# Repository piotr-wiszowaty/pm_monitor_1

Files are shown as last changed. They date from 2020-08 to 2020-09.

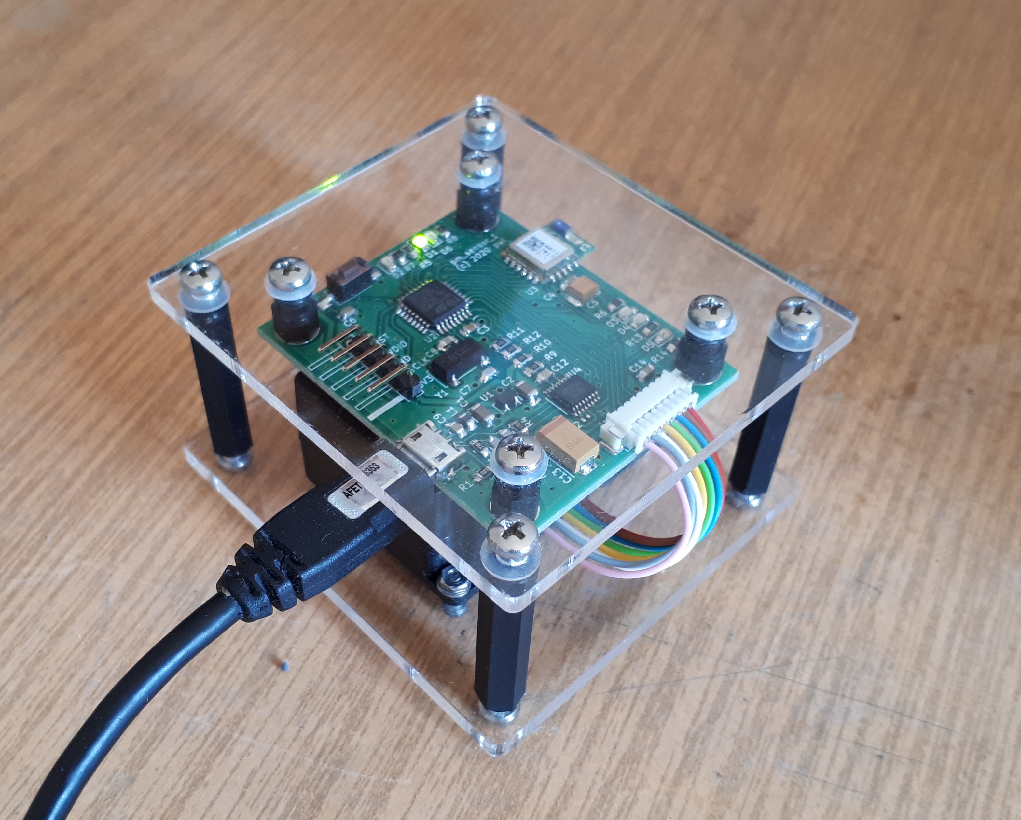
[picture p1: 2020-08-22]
pics/pm_monitor_1.jpg

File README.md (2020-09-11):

pm_monitor_1
============

A particulate matter monitor with BLE and UART interfaces.

The device is based on this [sensor](https://www.dfrobot.com/product-1272.html).
The measured particle concentrations are reported periodically over UART
(FDTI chip based interface) and over BLE. The included server listens for
the incoming BLE reports and stores them in an [InfluxDB](https://www.influxdata.com/) database.

Firmware
--------

The firmware is based on [Mecrisp-Stellaris Forth](http://mecrisp.sourceforge.net/).
Flashing firmware can be done using a communication program (minicom, picocom, etc):

0. flash the Mecrisp-Stellaris Forth core (see note below),
1. send `flash.forth`,
2. send `turnkey.forth`,
3. reset the device.

The microcontroller register and bit field constants can be downloaded from [here](https://github.com/piotr-wiszowaty/comfoh).

Note that to utilize hardware flow control (as in `uc/term.sh`) you need to enable USART2 RTS/CTS
lines in the Mecrisp-Stellaris Forth core.

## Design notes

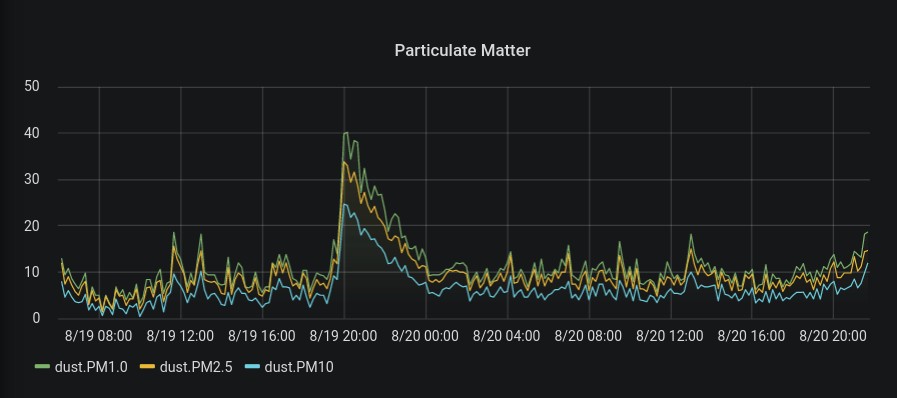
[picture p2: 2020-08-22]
pics/pm_plot.jpg

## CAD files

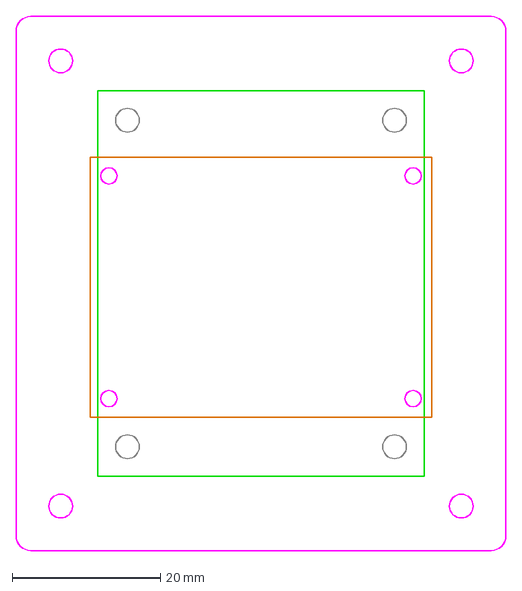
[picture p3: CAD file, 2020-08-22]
enclosure/pm_monitor_1.dxf
66.0 x 72.0 mm

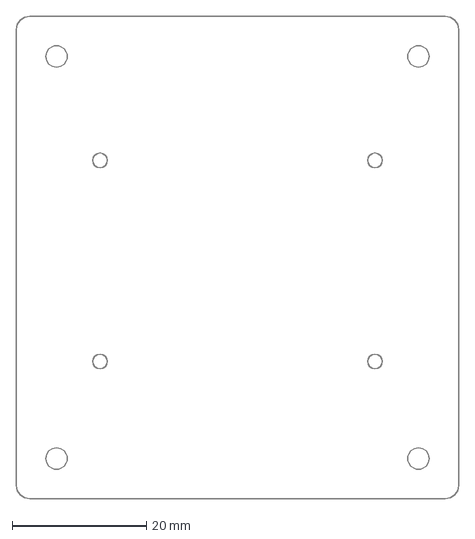
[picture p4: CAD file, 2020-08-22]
enclosure/pm_monitor_1_bot.dxf
66.0 x 72.0 mm

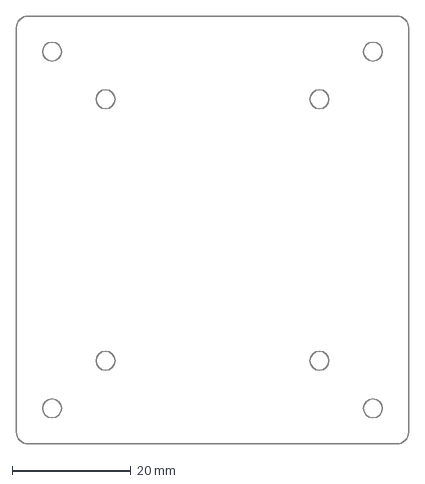
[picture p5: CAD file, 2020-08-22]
enclosure/pm_monitor_1_top.dxf
66.0 x 72.0 mm

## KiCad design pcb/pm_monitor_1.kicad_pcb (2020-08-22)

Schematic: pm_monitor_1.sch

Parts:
C1, C2: 1uF; C_1206_3216Metric_Pad1.42x1.75mm_HandSolder
C3, C9: 10nF; C_0805_2012Metric_Pad1.15x1.40mm_HandSolder
C4, C6, C12, C14: 100nF; C_0805_2012Metric_Pad1.15x1.40mm_HandSolder
C5: 10uF; CP_EIA-3528-21_Kemet-B_Pad1.50x2.35mm_HandSolder
C7, C8: 15pF; C_0805_2012Metric_Pad1.15x1.40mm_HandSolder
C10, C11: 47pF; C_0805_2012Metric_Pad1.15x1.40mm_HandSolder
C13: 330uF; CP_EIA-7343-31_Kemet-D_Pad2.25x2.55mm_HandSolder
D1: PWRLED; LED_0805_2012Metric_Pad1.15x1.40mm_HandSolder
D2, D6: LED; LED_0805_2012Metric_Pad1.15x1.40mm_HandSolder
D3: BTLED; LED_0805_2012Metric_Pad1.15x1.40mm_HandSolder
D4: TXLED; LED_0805_2012Metric_Pad1.15x1.40mm_HandSolder
D5: RXLED; LED_0805_2012Metric_Pad1.15x1.40mm_HandSolder
H1, H2, H3, H4: MountingHole; MountingHole_3.2mm_M3_Pad
J1: USB_B_Micro; USB_Micro-B_Molex_47346-0001
J2: SEN0177; Molex_PicoBlade_53261-0871_1x08-1MP_P1.25mm_Horizontal
J3: SWD; PinHeader_1x06_P2.54mm_Horizontal_HighProfile
L1: 600; L_0805_2012Metric_Pad1.15x1.40mm_HandSolder
R1: 100k; R_0805_2012Metric_Pad1.15x1.40mm_HandSolder
R2: 0; R_0402_1005Metric
R3, R4: 27; R_0805_2012Metric_Pad1.15x1.40mm_HandSolder
R5, R13: 100; R_0805_2012Metric_Pad1.15x1.40mm_HandSolder
R6, R7, R8, R14: 330; R_0805_2012Metric_Pad1.15x1.40mm_HandSolder
R9, R10, R11, R12: 10k; R_0805_2012Metric_Pad1.15x1.40mm_HandSolder
SW1: RESET; SW_SPST_FSMSM
U1: MCP1700-3302E_SOT23; SOT-23
U2: STM32G071KBT; LQFP-32_7x7mm_P0.8mm
U3: RN4871; Microchip_RN4871
U4: FT230XS; SSOP-16_3.9x4.9mm_P0.635mm
Y1: 32.768kHz; Crystal_SMD_Abracon_ABS25-4Pin_8.0x3.8mm

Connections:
+3V3: C2.1, C3.1, C4.1, C5.1, C12.1, D1.2, J3.1, R2.2, R6.1, R7.1, R8.1, R9.1, R10.1, R11.1, R12.1, R13.1, R14.1, U1.2, U2.4 (VDD/VDDA), U3.14, U4.3, U4.11
+5V: C1.1, C13.1, C14.2, J2.8, L1.2, U1.3, U4.12
/BLE_CTS#: U2.23 (PA12_[PA10]), U3.11
/BLE_MODE: U2.16 (PB1), U3.16
/BLE_RST#: U2.17 (PB2), U3.10
/BLE_RTS#: U2.22 (PA11_[PA9]), U3.9
/BLE_RX: U2.19 (PA9), U3.7
/BLE_TX: U2.21 (PA10), U3.8
/FTH_CTS#: R11.2, U2.7 (PA0), U4.2
/FTH_RTS#: R12.2, U2.8 (PA1), U4.6
/FTH_RXD: R9.2, U2.10 (PA3), U4.1
/FTH_TXD: R10.2, U2.9 (PA2), U4.4
/NRST: C6.1, J3.5, SW1.1, U2.6 (PF2-NRST)
/SENSOR_RESET: J2.3, U2.13 (PA6)
/SENSOR_RXD: J2.5
/SENSOR_SET: J2.6, U2.14 (PA7)
/SENSOR_TXD: J2.4, U2.15 (PB0)
/SWCLK: J3.2, U2.25 (PA14-BOOT0)
/SWDIO: J3.4, U2.24 (PA13)
/USBDM: R4.1, U4.9
/USBDP: R3.1, U4.8
/USB_N: C10.1, J1.2, R4.2
/USB_P: C11.1, J1.3, R3.2
/USB_PWREN#: U2.11 (PA4), U4.16
GND: C1.2, C2.2, C3.2, C4.2, C5.2, C6.2, C7.2, C8.2, C9.2, C10.2, C11.2, C12.2, C13.2, C14.1, J1.5, J1.6, J2.7, J3.3, R1.1, R5.2, SW1.2, U1.1, U2.5 (VSS/VSSA), U3.2, U3.13, U4.5, U4.13
unnamed: C7.1, U2.3 (PC15-OSC32_OUT), Y1.4
unnamed: C8.1, U2.2 (PC14-OSC32_IN), Y1.1
unnamed: C9.1, J1.1, L1.1
unnamed: D1.1, R5.1
unnamed: D2.1, U2.20 (PC6)
unnamed: D2.2, R7.2
unnamed: D3.1, U3.12
unnamed: D3.2, R6.2
unnamed: D4.1, U4.14
unnamed: D4.2, R13.2
unnamed: D5.1, U4.7
unnamed: D5.2, R14.2
unnamed: D6.1, U2.18 (PA8)
unnamed: D6.2, R8.2
unnamed: J1.4, R1.2
unnamed: R2.1, U4.10

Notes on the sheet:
(1) Mount to drive 3.3 V rail from the FT230X internal regulator (2) Do not mount when driving 3.3 V rail from FT230X internal regulator
Note (1)
Note (2)
green
red
yellow
blue

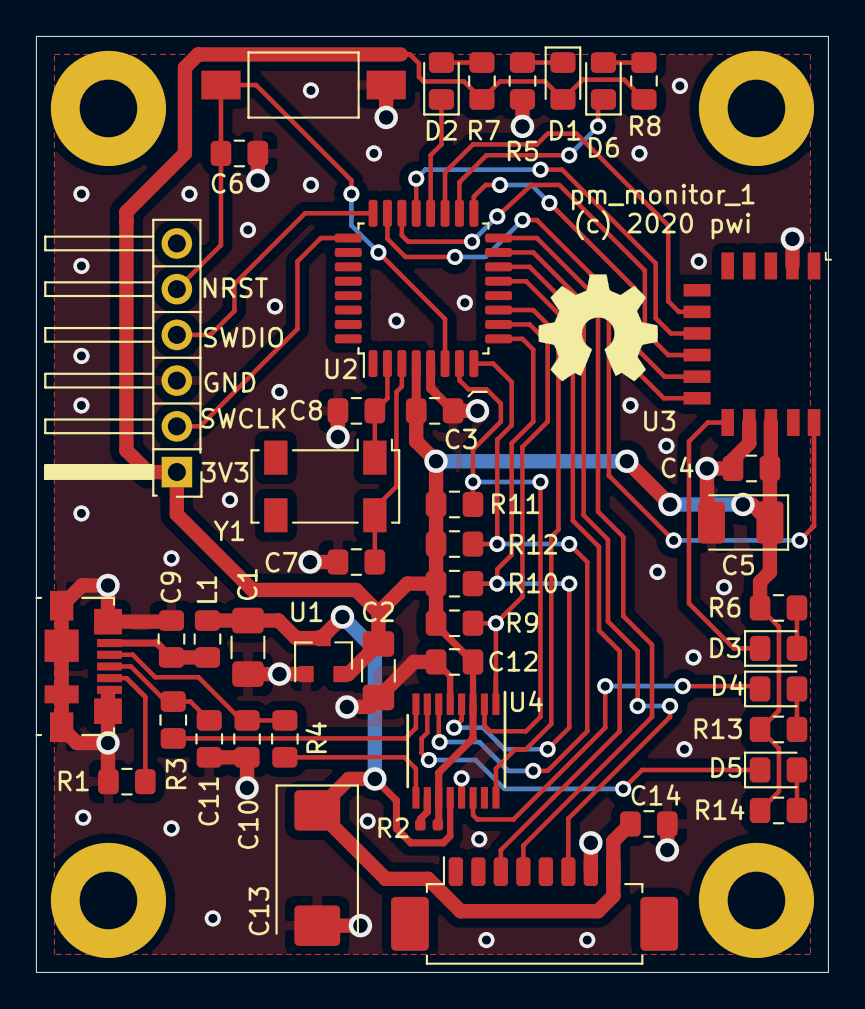
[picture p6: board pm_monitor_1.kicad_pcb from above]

Board: 2 copper layers, 44.0 x 52.0 mm, 48 parts (0 on the bottom side), 40 nets.

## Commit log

2020-08-22 Add PCB design files
    [pm_monitor_1.kicad_pcb, pm_monitor_1.sch]
2020-08-22 Add 'enclosure' design files
    [pm_monitor_1.dxf, pm_monitor_1_bot.dxf, pm_monitor_1_top.dxf]
2020-08-22 Add Gerber files
    [pm_monitor_1-B_Cu.gbr, pm_monitor_1-B_Mask.gbr, pm_monitor_1-Edge_Cuts.gbr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]
2020-08-22 Add a photo of the device
2020-08-22 Add sample plot
2020-09-07 Add UART pass-through functionality
    This is for updating RN4871 firmware with the IsUpdate tool.

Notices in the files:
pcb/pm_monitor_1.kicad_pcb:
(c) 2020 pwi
